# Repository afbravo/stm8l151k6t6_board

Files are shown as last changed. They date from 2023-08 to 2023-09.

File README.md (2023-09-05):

# STM8L151 Dev Board V2.0

This board was created with the intent to familiarize with the STM8 family of MCUs from ST Microcontroller.
The main features of this board are:

- Micro usb power input
- Power on led
- User led connected to PB0
- User button connected to PD7
- SWIM programming / debugging interface
- 8MHz High Speed External Clock
- 32.768 KHz Low Speed External Clock
- Reset Button
- Generick Male Headers for all I/O
- USB to UART converter
- Breadboard friendly
- 2 layer PCB for inexpensive manufacturing

## Version 2.0 Improvements

The following features were added/removed from the previous version:

- Increase resistor value for internal leds to reduce brightness.
- Added USB to UART converter.
- Reduced form factor to 18mm wide by 48mm long, in order to fit in a breadboard.
- Changed the male headers to use 2 1x16 headers instead of 4 1x8 headers.
- Male headers are spaced to fit in a breadboard.
- Kept backwards compatibility with the previous version on connection of internal peripherals.
- Mechanical mounting holes were changed to m2 2.2mm diameter holes.

The board was created using KiCad 6. It was mostly left up to the end user to decide its purspose
as it doesnt provide any internal sensors or ICs.

The DataSheet for the STM8L151K6T6 MCU: [datasheet](https://www.st.com/content/ccc/resource/technical/document/datasheet/43/12/db/4c/8b/08/4a/73/CD00240181.pdf/files/CD00240181.pdf/jcr:content/translations/en.CD002401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)

## Schematic

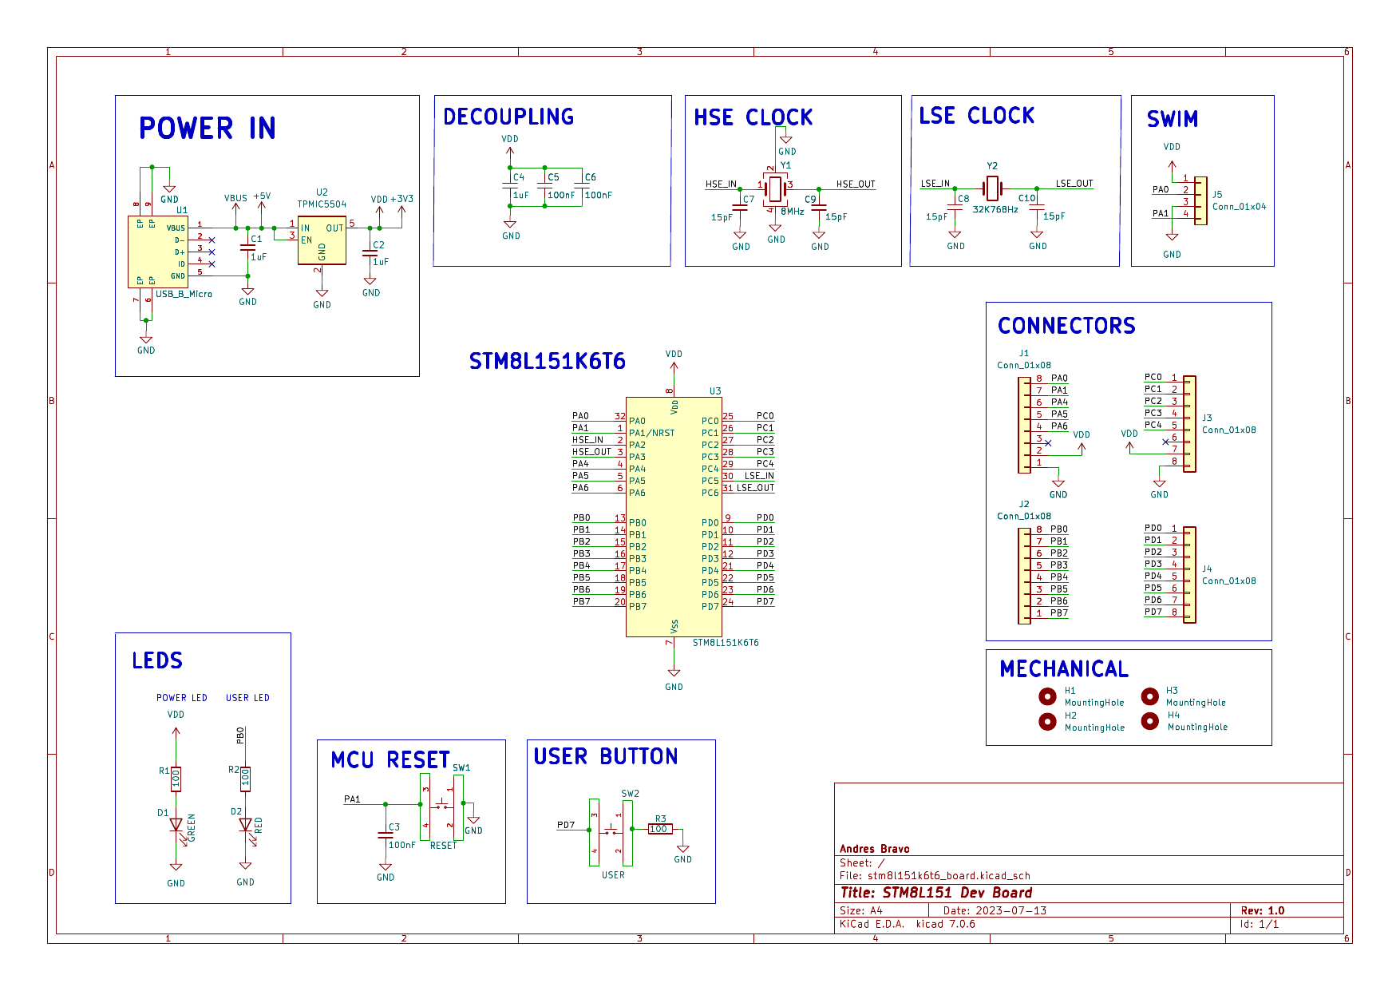
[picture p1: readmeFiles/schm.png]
schematic


## PCB

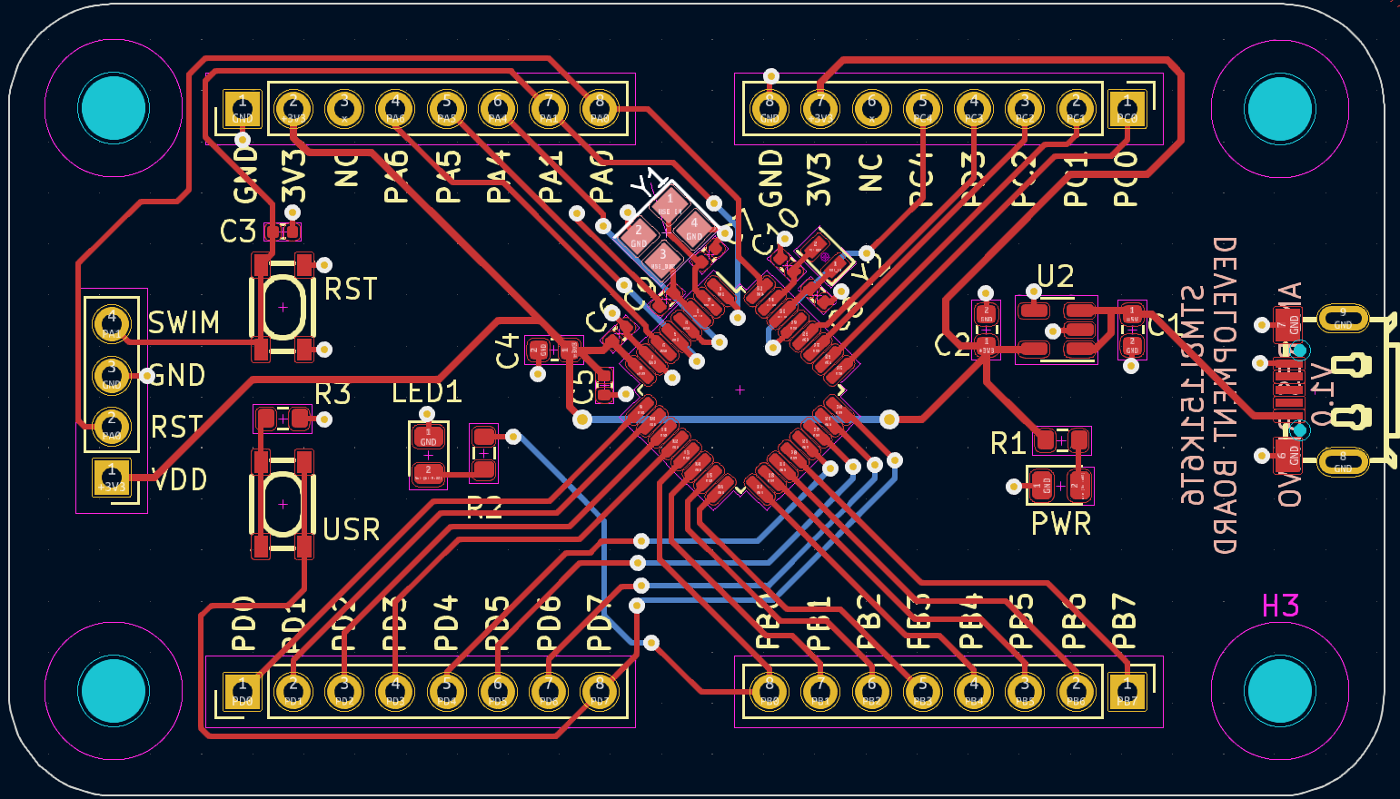
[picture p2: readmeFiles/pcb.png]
pcb


## Finished Board

board

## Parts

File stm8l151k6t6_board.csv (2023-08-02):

Ref | Qnty | Value | Cmp name | Footprint | Description | Vendor
C1, C2, C4, | 3 | 1uF | C_Small | Capacitor_SMD:C_0603_1608Metric | Unpolarized capacitor, small symbol
C3, C5, C6, | 3 | 100nF | C_Small | Capacitor_SMD:C_0402_1005Metric | Unpolarized capacitor, small symbol
C7, C8, C9, C10, | 4 | 15pF | C_Small | Capacitor_SMD:C_0402_1005Metric | Unpolarized capacitor, small symbol
D1, | 1 | GREEN | LED | LED_SMD:LED_0805_2012Metric | Light emitting diode
D2, | 1 | RED | LED | LED_SMD:LED_0805_2012Metric | Light emitting diode
H1, H2, H3, H4, | 4 | MountingHole | MountingHole | MountingHole:MountingHole_3.2mm_M3 | Mounting Hole without connection
J1, J2, J3, J4, | 4 | Conn_01x08 | Conn_01x08 | Connector_PinHeader_2.54mm:PinHeader_1x08_P2.54mm_Vertical | Generic connector, single row, 01x08, script generated (kicad-library-utils/schlib/autogen/connector/)
J5, | 1 | Conn_01x04 | Conn_01x04 | Connector_PinHeader_2.54mm:PinHeader_1x04_P2.54mm_Vertical | Generic connector, single row, 01x04, script generated (kicad-library-utils/schlib/autogen/connector/)
R1, R2, R3, | 3 | 100 | R | Resistor_SMD:R_0603_1608Metric | Resistor
SW1, | 1 | RESET | SKRPABE010 | Button_Switch_SMD:SW-SMD_4P-L4.2-W3.2-P2.20-LS4.6
SW2, | 1 | USER | SKRPABE010 | Button_Switch_SMD:SW-SMD_4P-L4.2-W3.2-P2.20-LS4.6
U1, | 1 | USB_B_Micro | MICRO_7_2JB | Connector_USB:MICRO-USB-SMD_MICRO-7.2JB
U2, | 1 | TPMIC5504 | TPMIC5504 | Package_TO_SOT_SMD:SOT-23-5 | 150-mA, 500nA Ultra-Low-IQ LDO, 3.3V, SOT-23-5
U3, | 1 | STM8L151K6T6 | STM8L151K6T6 | Package_QFP:LQFP-32_7x7mm_P0.8mm
Y1, | 1 | 8MHz | Crystal_GND24 | Crystal:Crystal_SMD_3225-4Pin_3.2x2.5mm | Four pin crystal, GND on pins 2 and 4
Y2, | 1 | 32K768Hz | Crystal | Crystal:Crystal_SMD_2012-2Pin_2.0x1.2mm | Two pin crystal

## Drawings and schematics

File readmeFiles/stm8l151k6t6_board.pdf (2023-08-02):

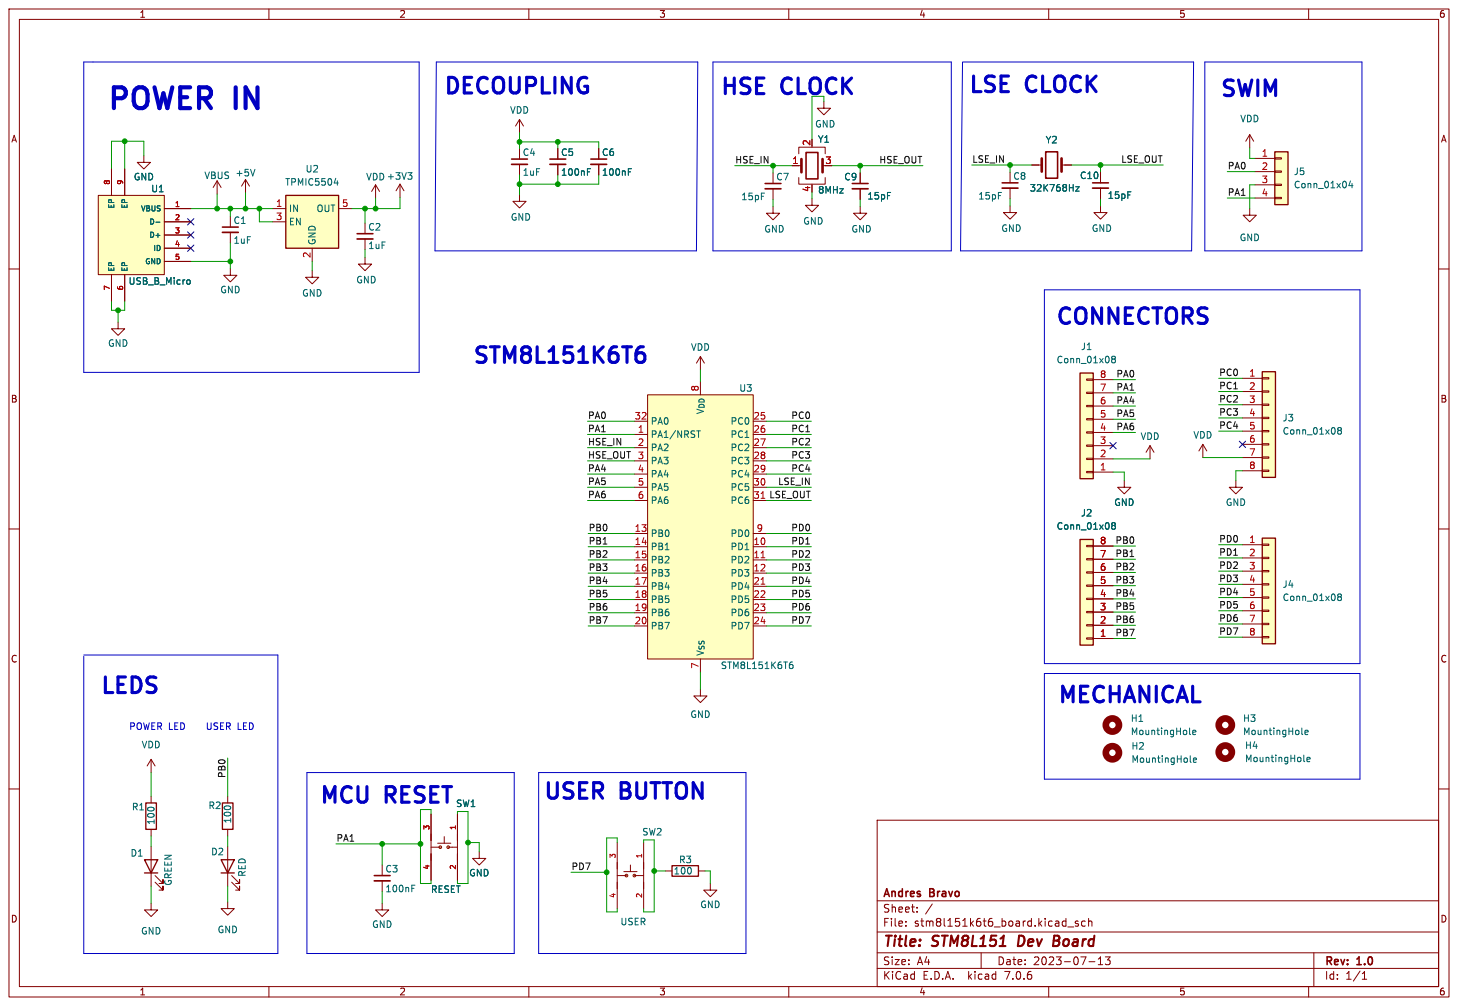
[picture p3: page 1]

Id: 1/1 Title: STM8L151 Dev Board

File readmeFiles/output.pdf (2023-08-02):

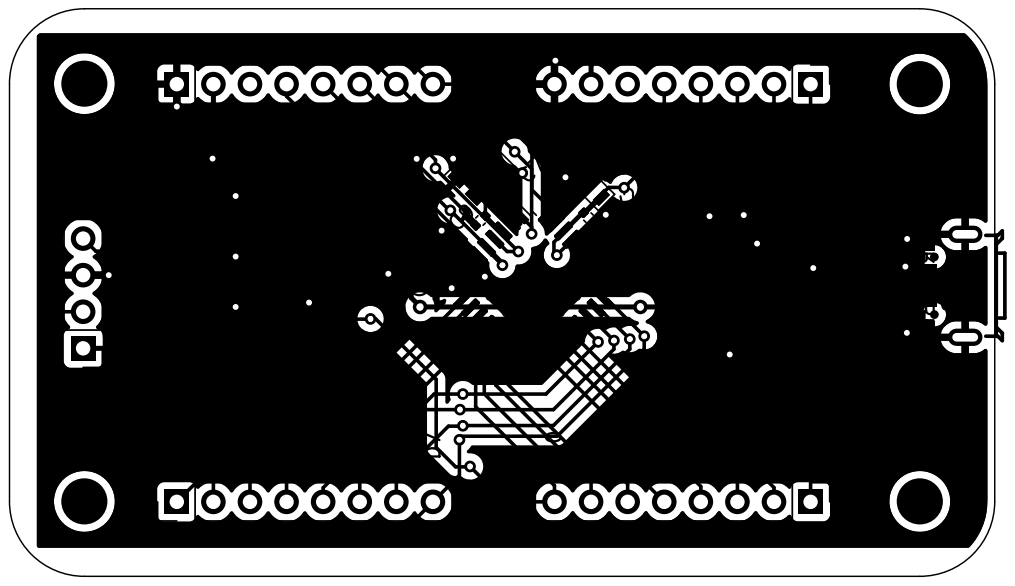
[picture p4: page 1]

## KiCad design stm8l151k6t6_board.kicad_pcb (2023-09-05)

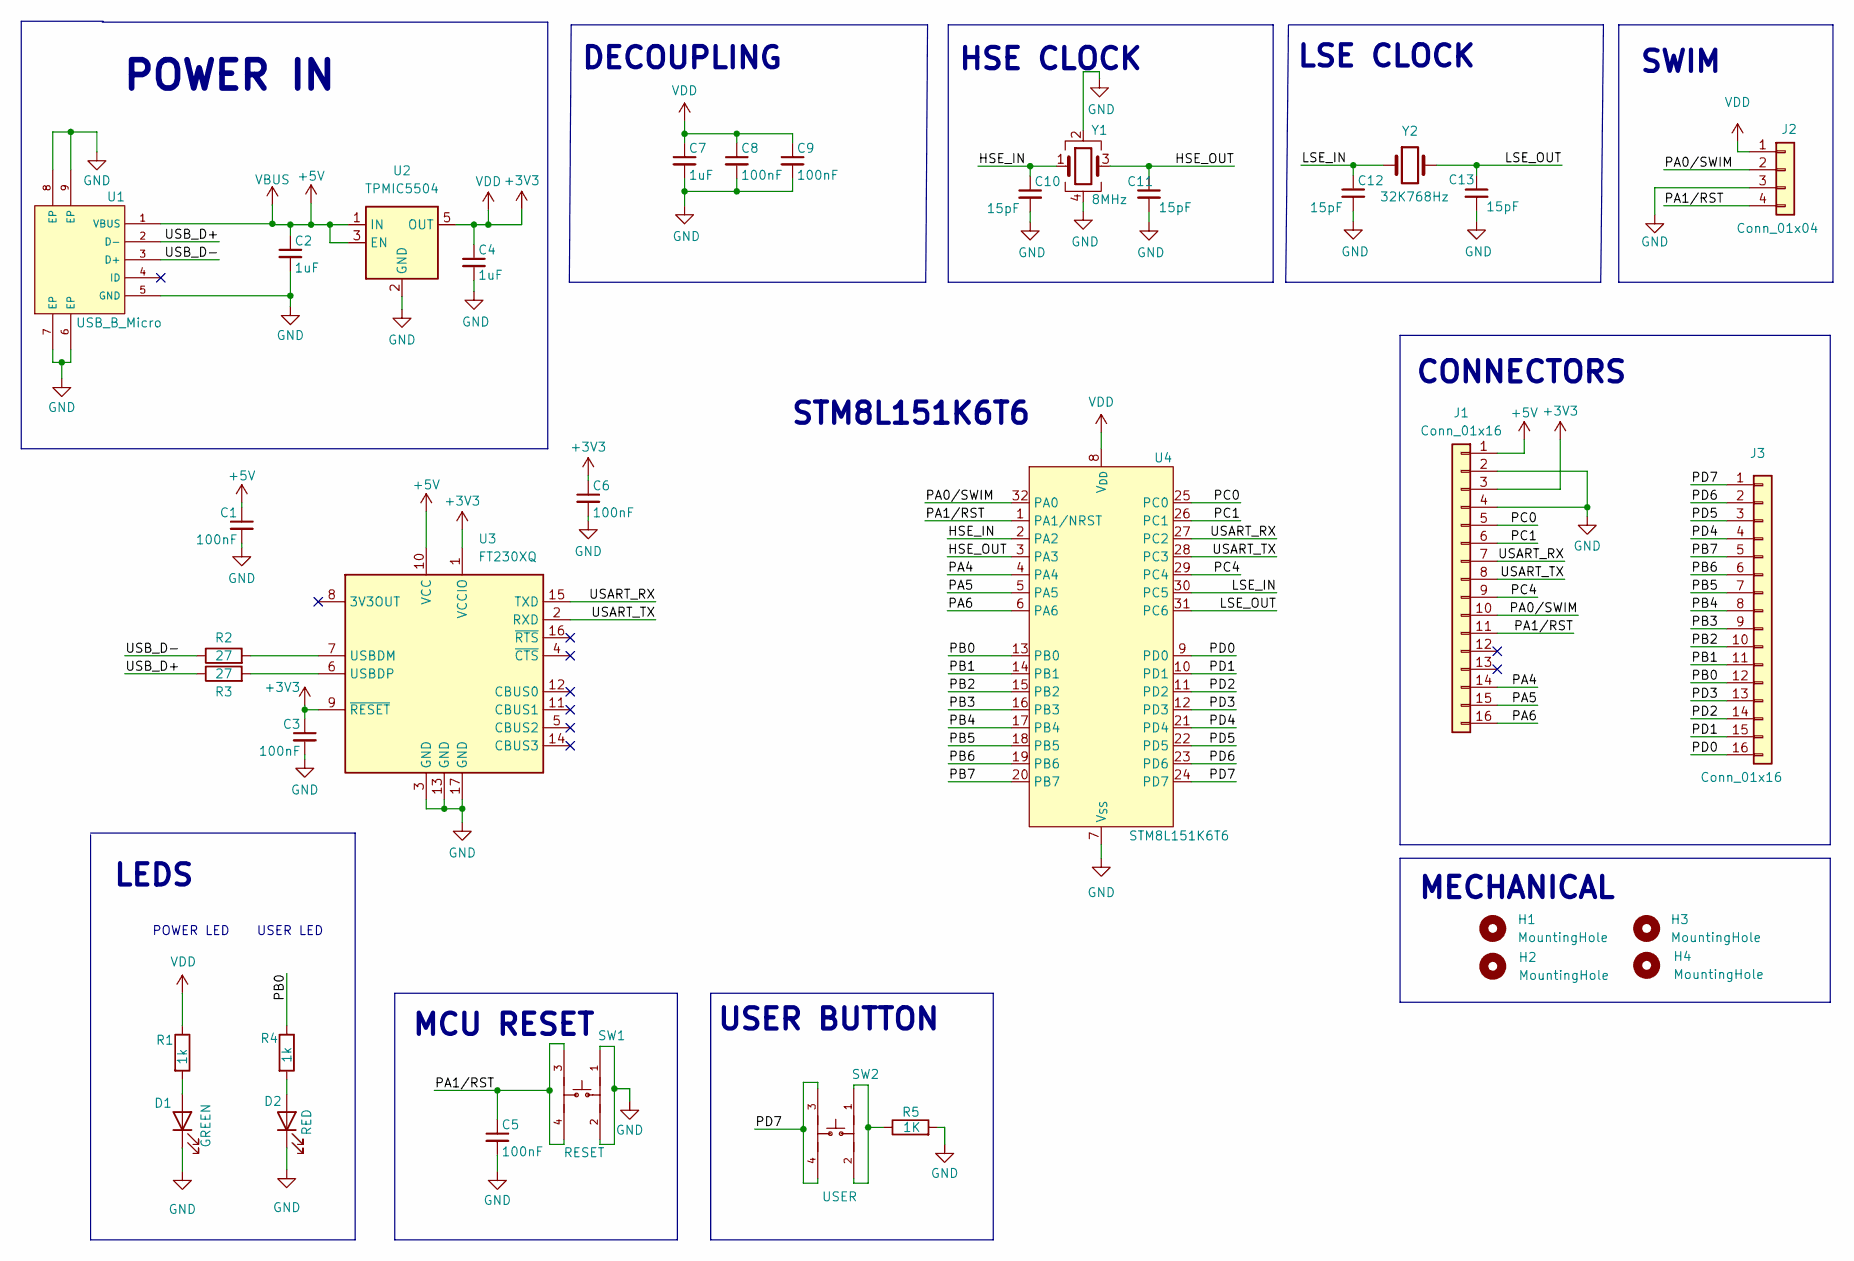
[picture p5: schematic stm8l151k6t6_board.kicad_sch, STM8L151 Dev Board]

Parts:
C1, C3, C5, C6, C8, C9: 100nF; C_0402_1005Metric; LCSC C106252
C2, C4, C7: 1uF; C_0603_1608Metric; LCSC C108463
C10, C11, C12, C13: 15pF; C_0402_1005Metric; LCSC C295959
D1: GREEN; LED_0805_2012Metric; LCSC C84257
D2: RED; LED_0805_2012Metric; LCSC C113551
H1, H2, H3, H4: MountingHole; MountingHole_2.2mm_M2
J1, J3: Conn_01x16; PinHeader_1x16_P2.54mm_Vertical
J2: Conn_01x04; PinHeader_1x04_P2.54mm_Vertical
R1, R4: 1k; R_0603_1608Metric
R2, R3: 27; R_0805_2012Metric; LCSC C352233
R5: 1K; R_0603_1608Metric; LCSC C5139650
SW1: RESET; SW-SMD_4P-L4.2-W3.2-P2.20-LS4.6; LCSC C115360
SW2: USER; SW-SMD_4P-L4.2-W3.2-P2.20-LS4.6; LCSC C115360
U1: USB_B_Micro; MICRO-USB-SMD_MICRO-7.2JB; LCSC C2681559
U2: TPMIC5504; SOT-23-5; LCSC C3021093
U3: FT230XQ; QFN-16-1EP_4x4mm_P0.65mm_EP2.1x2.1mm; LCSC C128629
U4: STM8L151K6T6; LQFP-32_7x7mm_P0.8mm; LCSC C8259
Y1: 8MHz; Crystal_SMD_3225-4Pin_3.2x2.5mm; LCSC C524715
Y2: 32K768Hz; Crystal_SMD_2012-2Pin_2.0x1.2mm; LCSC C90943

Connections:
+3V3: C3.1, C4.1, C6.1, C7.1, C8.1, C9.1, J1.3, J2.1, R1.1, U2.5 (OUT), U3.1 (VCCIO), U3.9 (~RESET), U4.8 (V_{DD})
+5V: C1.1, C2.1, J1.1, U1.1 (VBUS), U2.1 (IN), U2.3 (EN), U3.10 (VCC)
/HSE_IN: C10.1, U4.2 (PA2), Y1.1
/HSE_OUT: C11.1, U4.3 (PA3), Y1.3
/LSE_IN: C12.1, U4.30 (PC5), Y2.1
/LSE_OUT: C13.1, U4.31 (PC6), Y2.2
/PA0/SWIM: J1.10, J2.2, U4.32 (PA0)
/PA1/RST: C5.1, J1.11, J2.4, SW1.3, SW1.4, U4.1 (PA1/NRST)
/PA4: J1.14, U4.4 (PA4)
/PA5: J1.15, U4.5 (PA5)
/PA6: J1.16, U4.6 (PA6)
/PB0: J3.12, R4.1, U4.13 (PB0)
/PB1: J3.11, U4.14 (PB1)
/PB2: J3.10, U4.15 (PB2)
/PB3: J3.9, U4.16 (PB3)
/PB4: J3.8, U4.17 (PB4)
/PB5: J3.7, U4.18 (PB5)
/PB6: J3.6, U4.19 (PB6)
/PB7: J3.5, U4.20 (PB7)
/PC0: J1.5, U4.25 (PC0)
/PC1: J1.6, U4.26 (PC1)
/PC4: J1.9, U4.29 (PC4)
/PD0: J3.16, U4.9 (PD0)
/PD1: J3.15, U4.10 (PD1)
/PD2: J3.14, U4.11 (PD2)
/PD3: J3.13, U4.12 (PD3)
/PD4: J3.4, U4.21 (PD4)
/PD5: J3.3, U4.22 (PD5)
/PD6: J3.2, U4.23 (PD6)
/PD7: J3.1, SW2.3, SW2.4, U4.24 (PD7)
/USART_RX: J1.7, U3.15 (TXD), U4.27 (PC2)
/USART_TX: J1.8, U3.2 (RXD), U4.28 (PC3)
/USB_D+: R3.1, U1.2 (D-)
/USB_D-: R2.1, U1.3 (D+)
GND: C1.2, C2.2, C3.2, C4.2, C5.2, C6.2, C7.2, C8.2, C9.2, C10.2, C11.2, C12.2, C13.2, D1.1 (K), D2.1 (K), J1.2, J1.4, J2.3, R5.2, SW1.1, SW1.2, U1.5 (GND), U1.6 (EP), U1.7 (EP), U1.8 (EP), U1.9 (EP), U2.2 (GND), U2.4 (GND), U3.3 (GND), U3.13 (GND), U3.17 (GND), U4.7 (V_{SS}), Y1.2, Y1.4
unnamed: D1.2 (A), R1.2
unnamed: D2.2 (A), R4.2
unnamed: R5.1, SW2.1, SW2.2
unnamed: R2.2, U3.7 (USBDM)
unnamed: R3.2, U3.6 (USBDP)

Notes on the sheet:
POWER LED
LSE CLOCK
STM8L151K6T6
SWIM
HSE CLOCK
CONNECTORS
MCU RESET
USER BUTTON
POWER IN
USER LED
LEDS
DECOUPLING
MECHANICAL

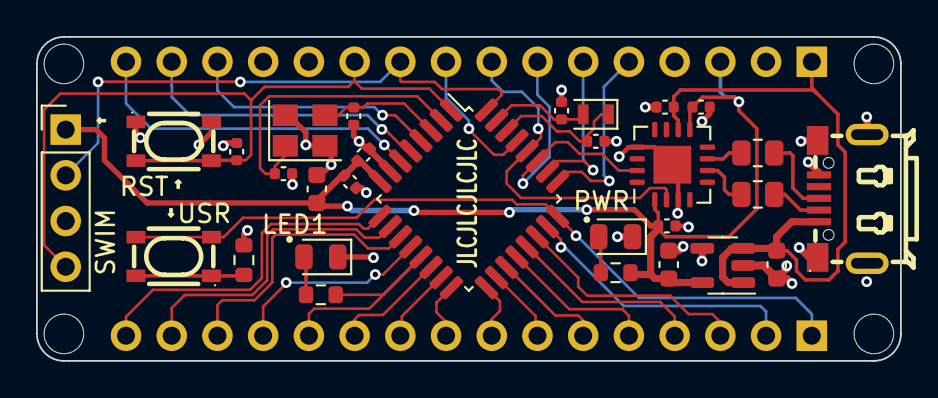
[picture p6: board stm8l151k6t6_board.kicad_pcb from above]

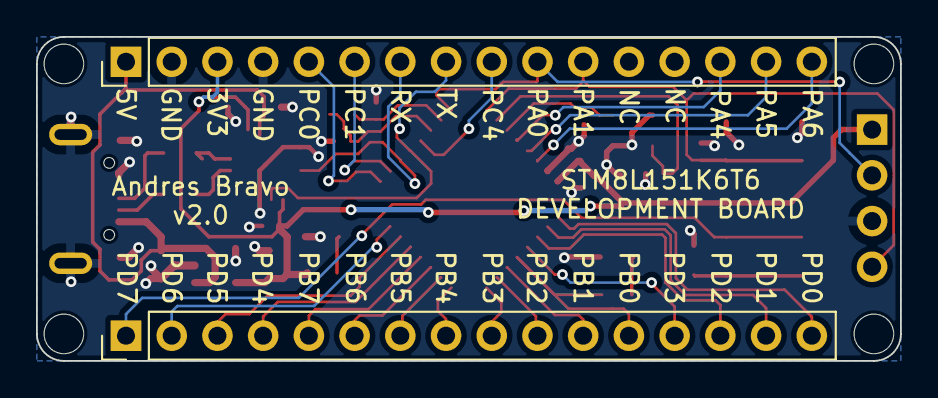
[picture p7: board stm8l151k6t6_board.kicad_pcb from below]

Board: 2 copper layers, 48.0 x 18.0 mm, 35 parts (2 on the bottom side), 40 nets.

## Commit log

2023-08-02 added pcb img
2023-09-05 updated version
    [stm8Dev_BOM.csv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]
